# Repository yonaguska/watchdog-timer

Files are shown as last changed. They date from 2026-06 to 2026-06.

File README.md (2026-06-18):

# watchdog-timer
A retriggerable monostable based on the ICM7555, useful in watchdog applications for microcontrollers. 

To use the watchdog;
1. Have your code generate a short negative RESET signal to the watchdog, to initialize the circuit.
 NOTE: there is a capacitor to GND that should initialize the watchdog at power-on.
2. The watchdog has a timeout of about 400 seconds, at which time it will drive the OUTPUT LOW. In addition to the OUPUT signal, a capacitivly-coupled PULSE will temporarily go LOW.
3. To keep the watchdog from timing out, generate a short LOW pulse to the /TRIGGER pin before the 400 seconds is up.

watchdog waveforms

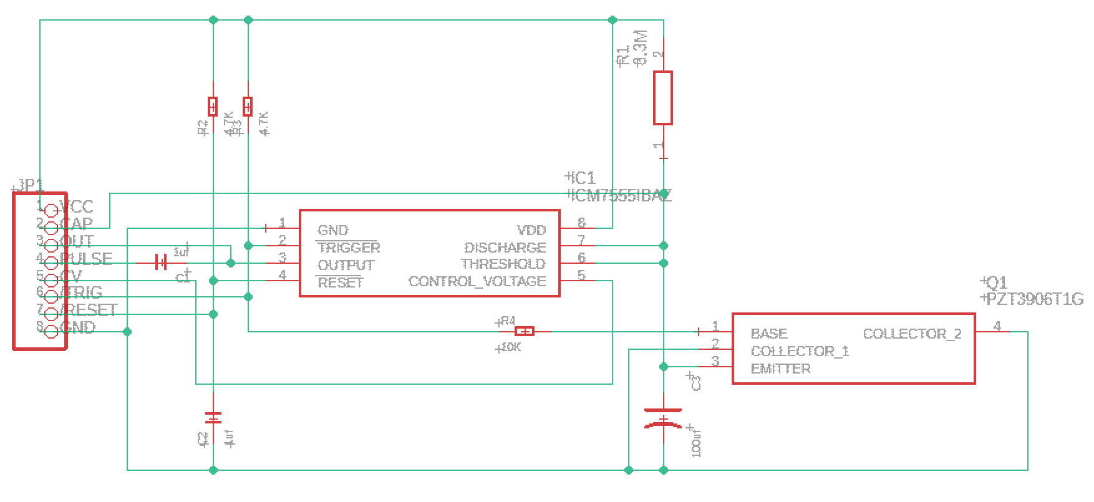
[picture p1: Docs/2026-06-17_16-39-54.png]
watchdog schematic


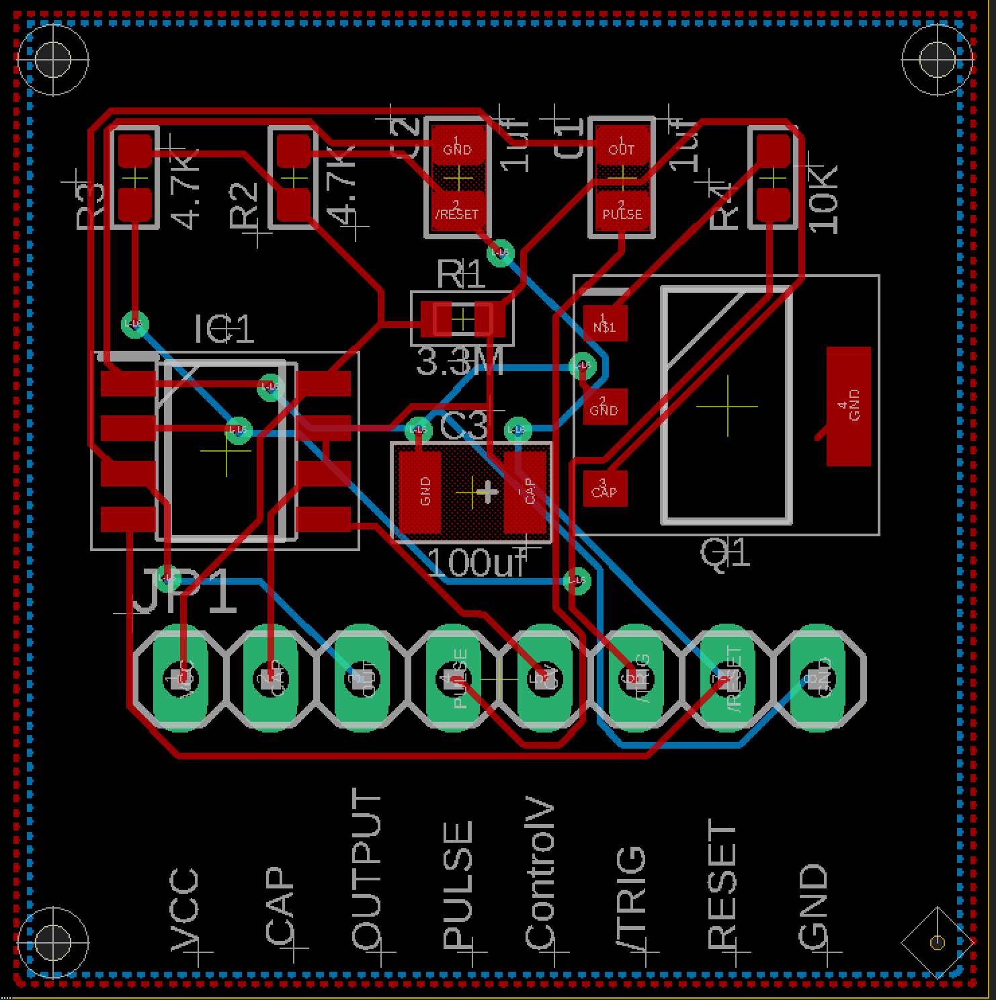
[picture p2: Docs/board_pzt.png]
watchdog board


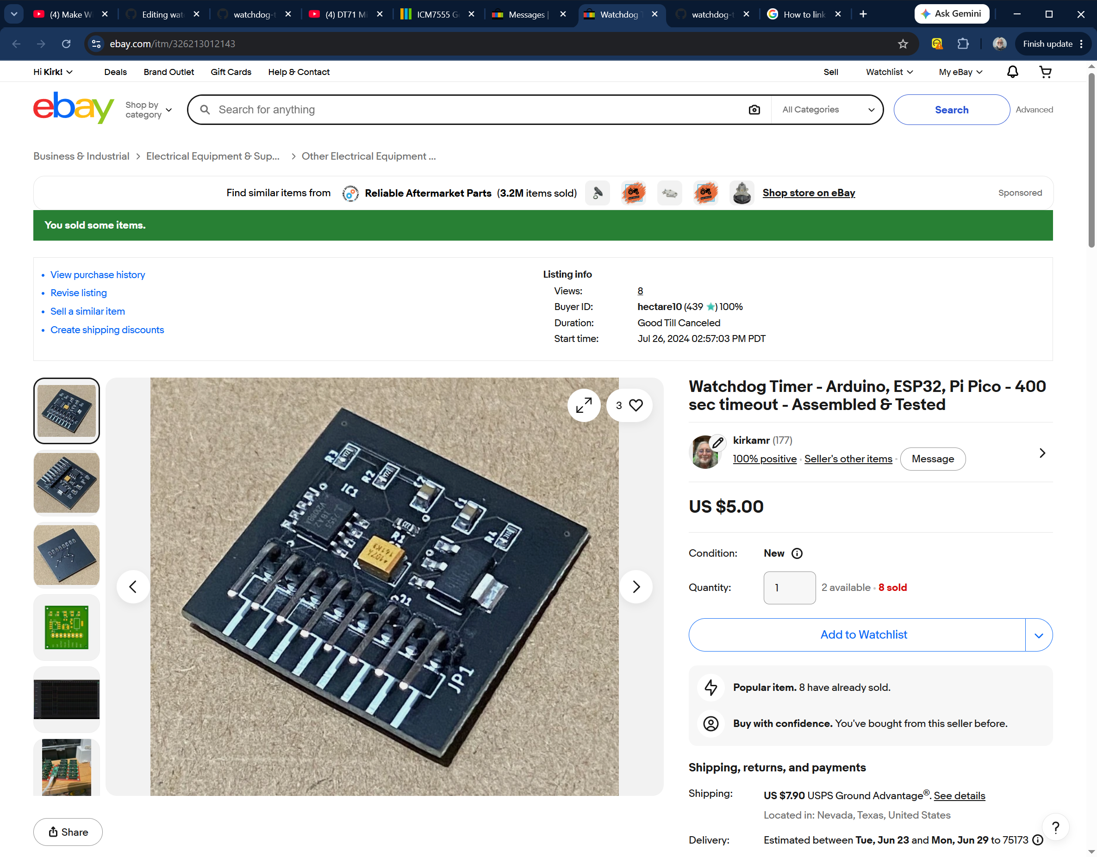
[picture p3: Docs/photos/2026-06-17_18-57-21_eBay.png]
watchdog photo


NXP ICM7555 Datasheet

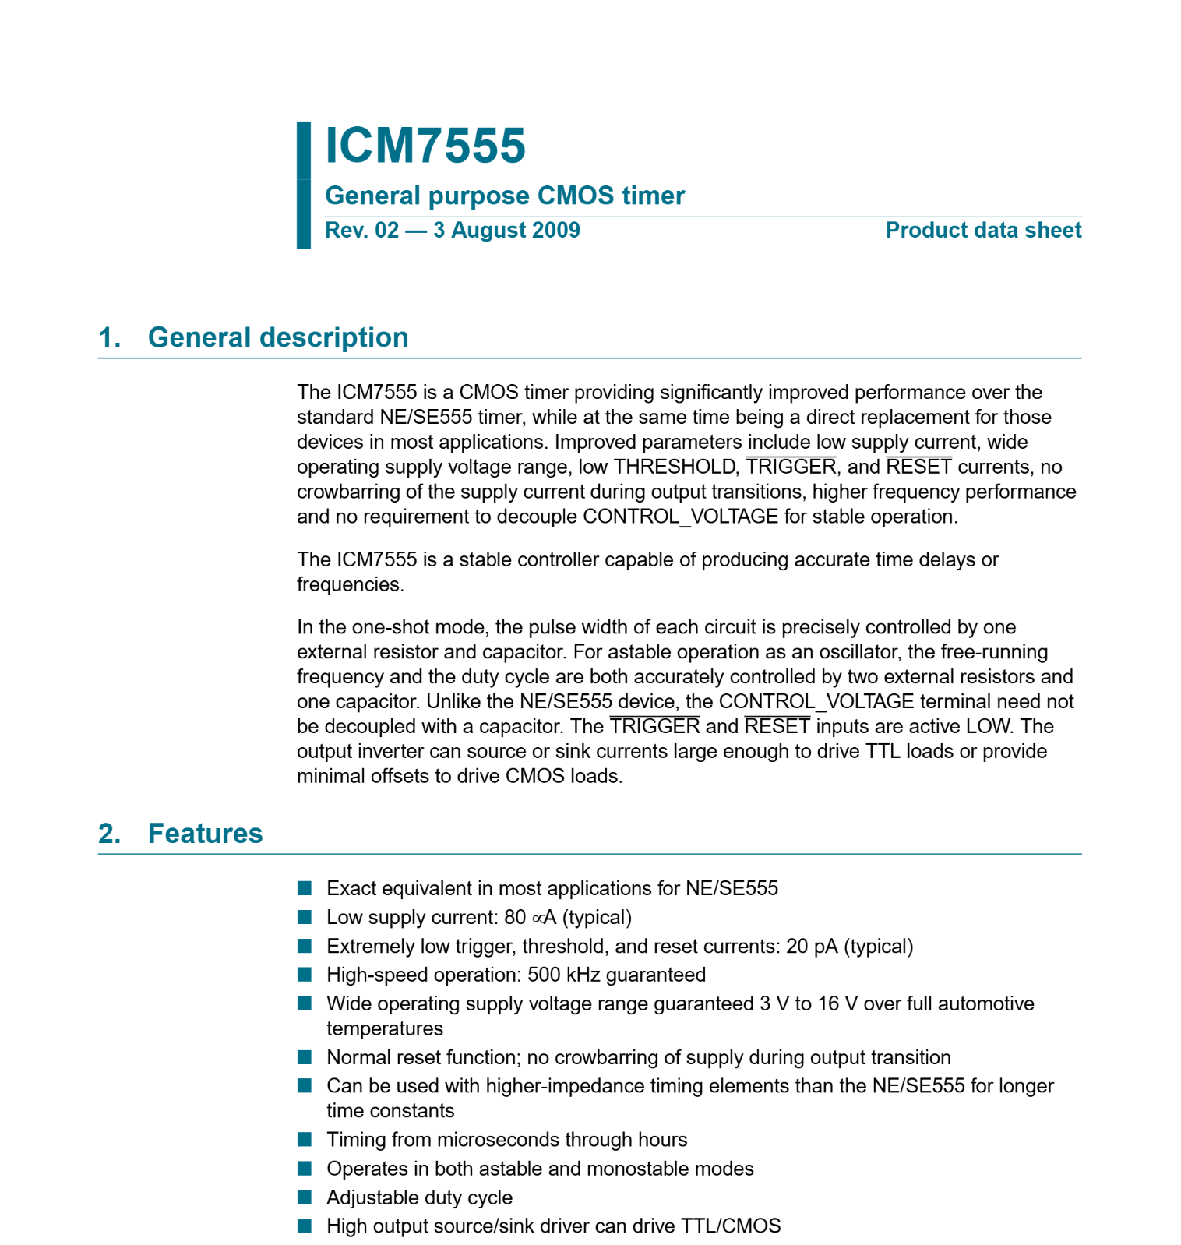
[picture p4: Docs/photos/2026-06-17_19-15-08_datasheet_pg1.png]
NXP ICM7555 Datasheet


Testing the watchdog units:

1. A Raspberry Pi Pico based test system was developed that runs tests on each watchdog I sell. Besides being a hardware/software developer, I am a professional test engineer with over thirty years of automated system test development experience.
2. The testing checks to insure the timeout period is at least 400 seconds, any board timing out in less than 400 seconds is rejected. It also insures the retriggering works ten times consecutively and then times out properly.

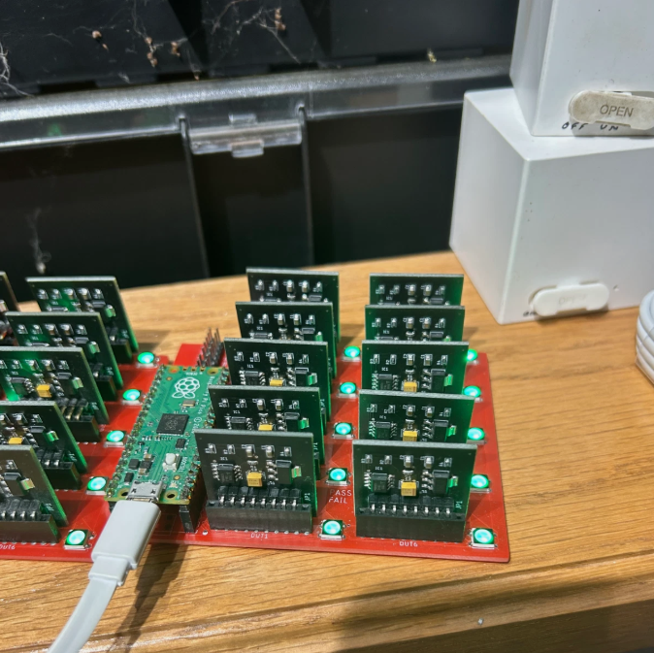
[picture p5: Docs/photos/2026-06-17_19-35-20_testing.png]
Test system


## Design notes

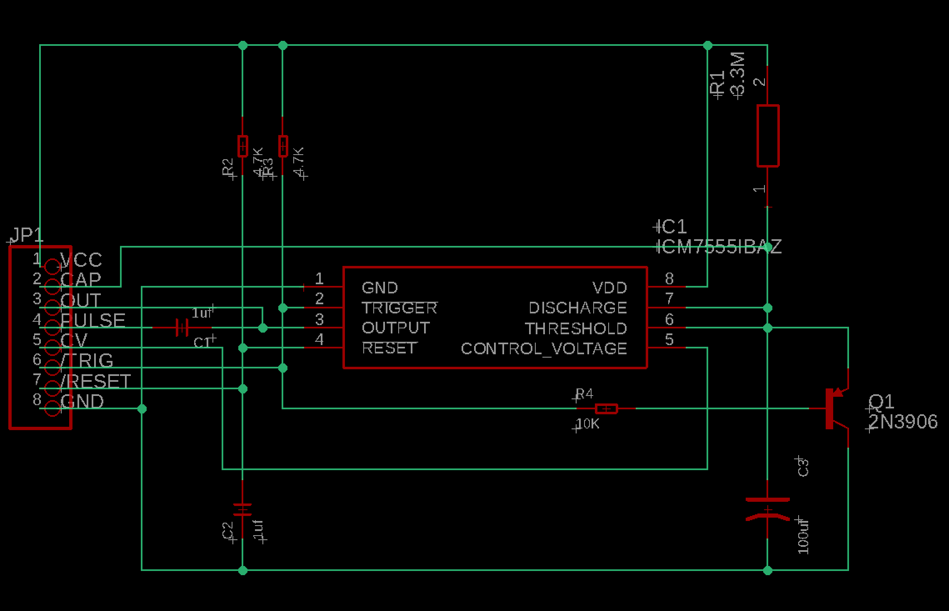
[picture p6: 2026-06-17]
Docs/schematic.png

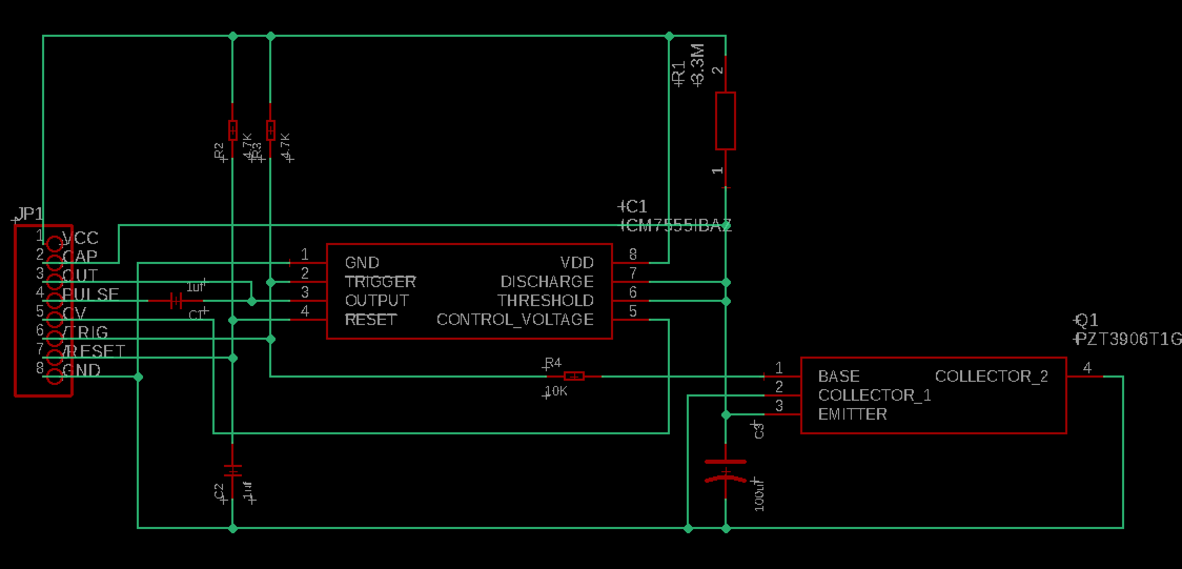
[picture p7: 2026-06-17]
Docs/schematic pzt3906.png

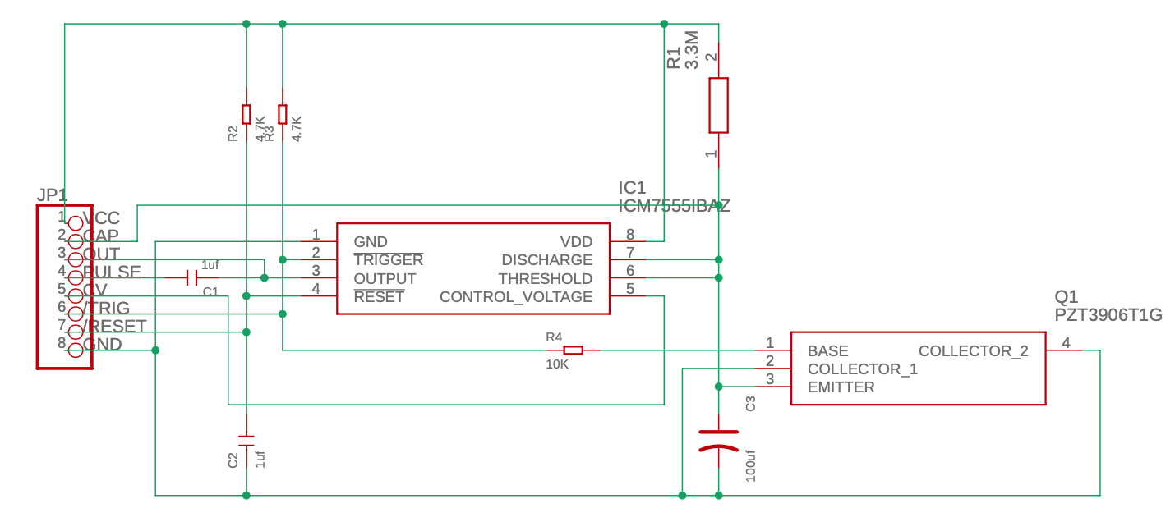
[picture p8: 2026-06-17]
Docs/schematic_on_white.png

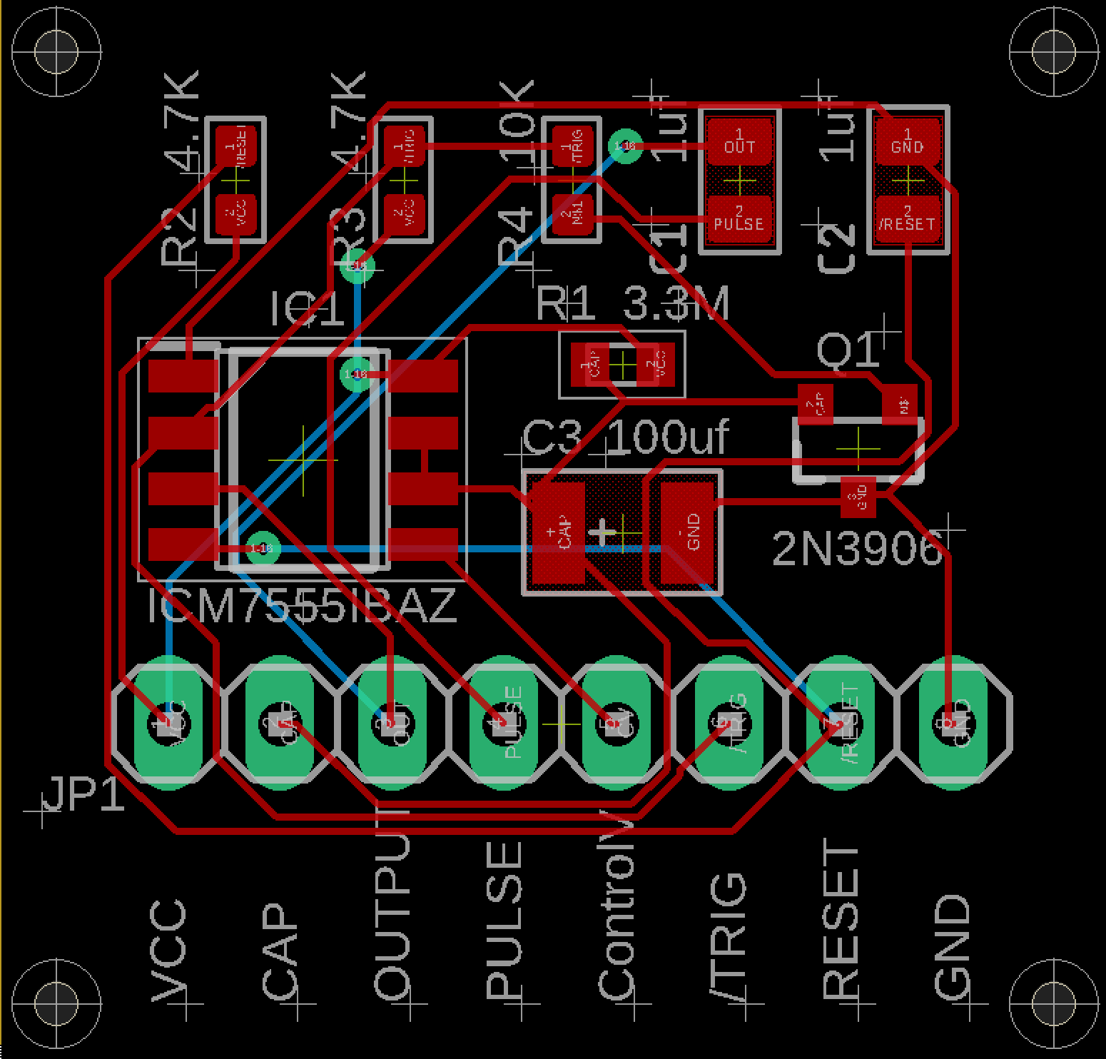
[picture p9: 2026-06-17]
Docs/board.png

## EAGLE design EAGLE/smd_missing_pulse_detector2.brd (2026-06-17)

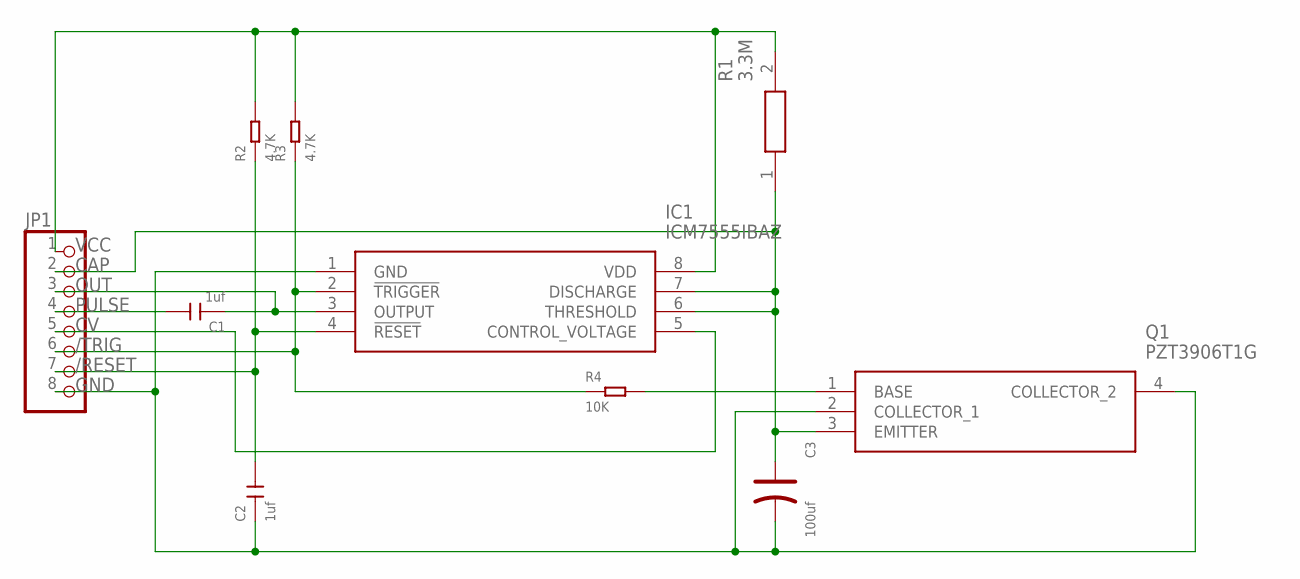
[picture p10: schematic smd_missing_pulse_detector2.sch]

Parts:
C1, C2: 1uf; C0805
C3: 100uf; AVX-B
IC1: ICM7555IBAZ; SOIC127P600X175-8N
JP1: PINHD-1X8; 1X08
Q1: PZT3906T1G; SOT230P700X175-4N
R1: 3.3M; RESC1608X50N
R2, R3: 4.7K; R0603
R4: 10K; R0603

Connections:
/RESET: C2.2, IC1.4 (!RESET), JP1.7, R2.1
/TRIG: IC1.2 (!TRIGGER), JP1.6, R3.1, R4.1
CAP: C3.+, IC1.6 (THRESHOLD), IC1.7 (DISCHARGE), JP1.2, Q1.3 (EMITTER), R1.1
CV: IC1.5 (CONTROL_VOLTAGE), JP1.5
GND: C2.1, C3.-, IC1.1 (GND), JP1.8, Q1.2 (COLLECTOR_1), Q1.4 (COLLECTOR_2)
unnamed: Q1.1 (BASE), R4.2
OUT: C1.1, IC1.3 (OUTPUT), JP1.3
PULSE: C1.2, JP1.4
VCC: IC1.8 (VDD), JP1.1, R1.2, R2.2, R3.2

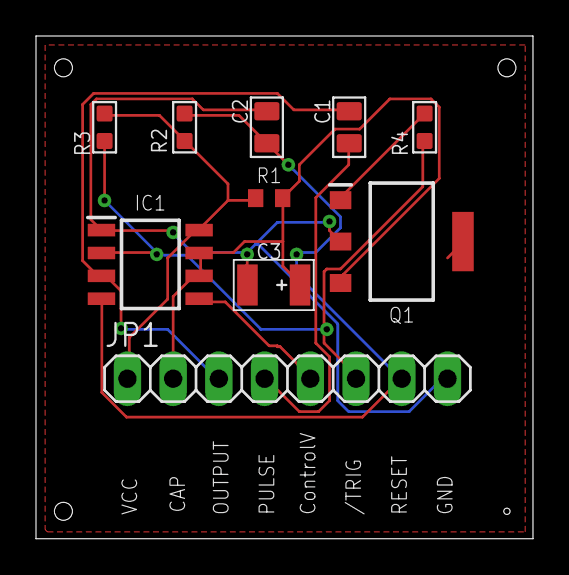
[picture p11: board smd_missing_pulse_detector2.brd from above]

Board: 2 copper layers, 27.6 x 27.9 mm, 10 parts (0 on the bottom side), 9 nets.

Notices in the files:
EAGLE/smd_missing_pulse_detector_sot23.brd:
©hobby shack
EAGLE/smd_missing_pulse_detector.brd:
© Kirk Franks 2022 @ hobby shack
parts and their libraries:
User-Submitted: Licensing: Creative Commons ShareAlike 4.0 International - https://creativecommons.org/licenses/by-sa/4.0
